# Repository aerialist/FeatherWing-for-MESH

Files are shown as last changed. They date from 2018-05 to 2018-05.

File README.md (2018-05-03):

# FeatherWing-for-MESH

A board to connect Adafruit Feather line of microcontroller boards to Sony MESH GPIO tag.

* https://www.adafruit.com/feather
* http://meshprj.com/en/

It also acts as a GPIO accessory for Sony MESH GPIO tag, featuring three buttons for Digital In, three LED's for Digital Out, a potentiometer for Analog In and another LED for PWM Out.

See [Wiki](https://github.com/aerialist/FeatherWing-for-MESH/wiki) for documentation.

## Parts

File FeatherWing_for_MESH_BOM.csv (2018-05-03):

Part | Value | Device | Package | Description
B1 |  | SWITCH_TACT_SMT4.6X2.8 | BTN_KMR2_4.6X2.8 | SMT Tact Switches
B2 |  | SWITCH_TACT_SMT4.6X2.8 | BTN_KMR2_4.6X2.8 | SMT Tact Switches
B3 |  | SWITCH_TACT_SMT4.6X2.8 | BTN_KMR2_4.6X2.8 | SMT Tact Switches
J1 | NF | CONN_05X2NO_SILK | 2X5_NOSILK | Multi connection point. Often used as Generic Header-pin footprint for 0.1 inch spaced/style header connections
J2 | NF | CONN_05X2NO_SILK | 2X5_NOSILK | Multi connection point. Often used as Generic Header-pin footprint for 0.1 inch spaced/style header connections
JP1 | JUMPER-SMT_2_NC_TRACE_SILK | JUMPER-SMT_2_NC_TRACE_SILK | SMT-JUMPER_2_NC_TRACE_SILK | Normally closed trace jumper
JP2 | JUMPER-SMT_3_1-NC_TRACE_SILK | JUMPER-SMT_3_1-NC_TRACE_SILK | SMT-JUMPER_3_1-NC_TRACE_SILK | Normally closed trace jumper (1 of 2 connections)
JP3 | NF | HEADER-1X16_76MIL | 1X16_ROUND_76MIL | PIN HEADER
JP4 | NF | HEADER-1X1276MIL | 1X12_ROUND_76MIL
LED1 | RED | LEDCHIPLED_0805 | CHIPLED_0805 | LED
LED2 | YELLOW | LEDCHIPLED_0805 | CHIPLED_0805 | LED
LED3 | GREEN | LEDCHIPLED_0805 | CHIPLED_0805 | LED
LED4 | RED | LEDCHIPLED_0805 | CHIPLED_0805 | LED
LED5 | ORANGE | LEDCHIPLED_0805 | CHIPLED_0805 | LED
MS1 | FEATHERWING | FEATHERWING | FEATHERWING
R1 | 280R | RESISTOR0805_NOTHERMALS | 0805_NOTHERMALS | Resistors
R2 | 330R | RESISTOR0805_NOTHERMALS | 0805_NOTHERMALS | Resistors
R3 | 220R | RESISTOR0805_NOTHERMALS | 0805_NOTHERMALS | Resistors
R4 | 280R | RESISTOR0805_NOTHERMALS | 0805_NOTHERMALS | Resistors
R5 | 330R | RESISTOR0805_NOTHERMALS | 0805_NOTHERMALS | Resistors
TM1 | 10kR | TRIMPOTTC33X | TC33X | SMT trimmer potentiometer part number TC33X

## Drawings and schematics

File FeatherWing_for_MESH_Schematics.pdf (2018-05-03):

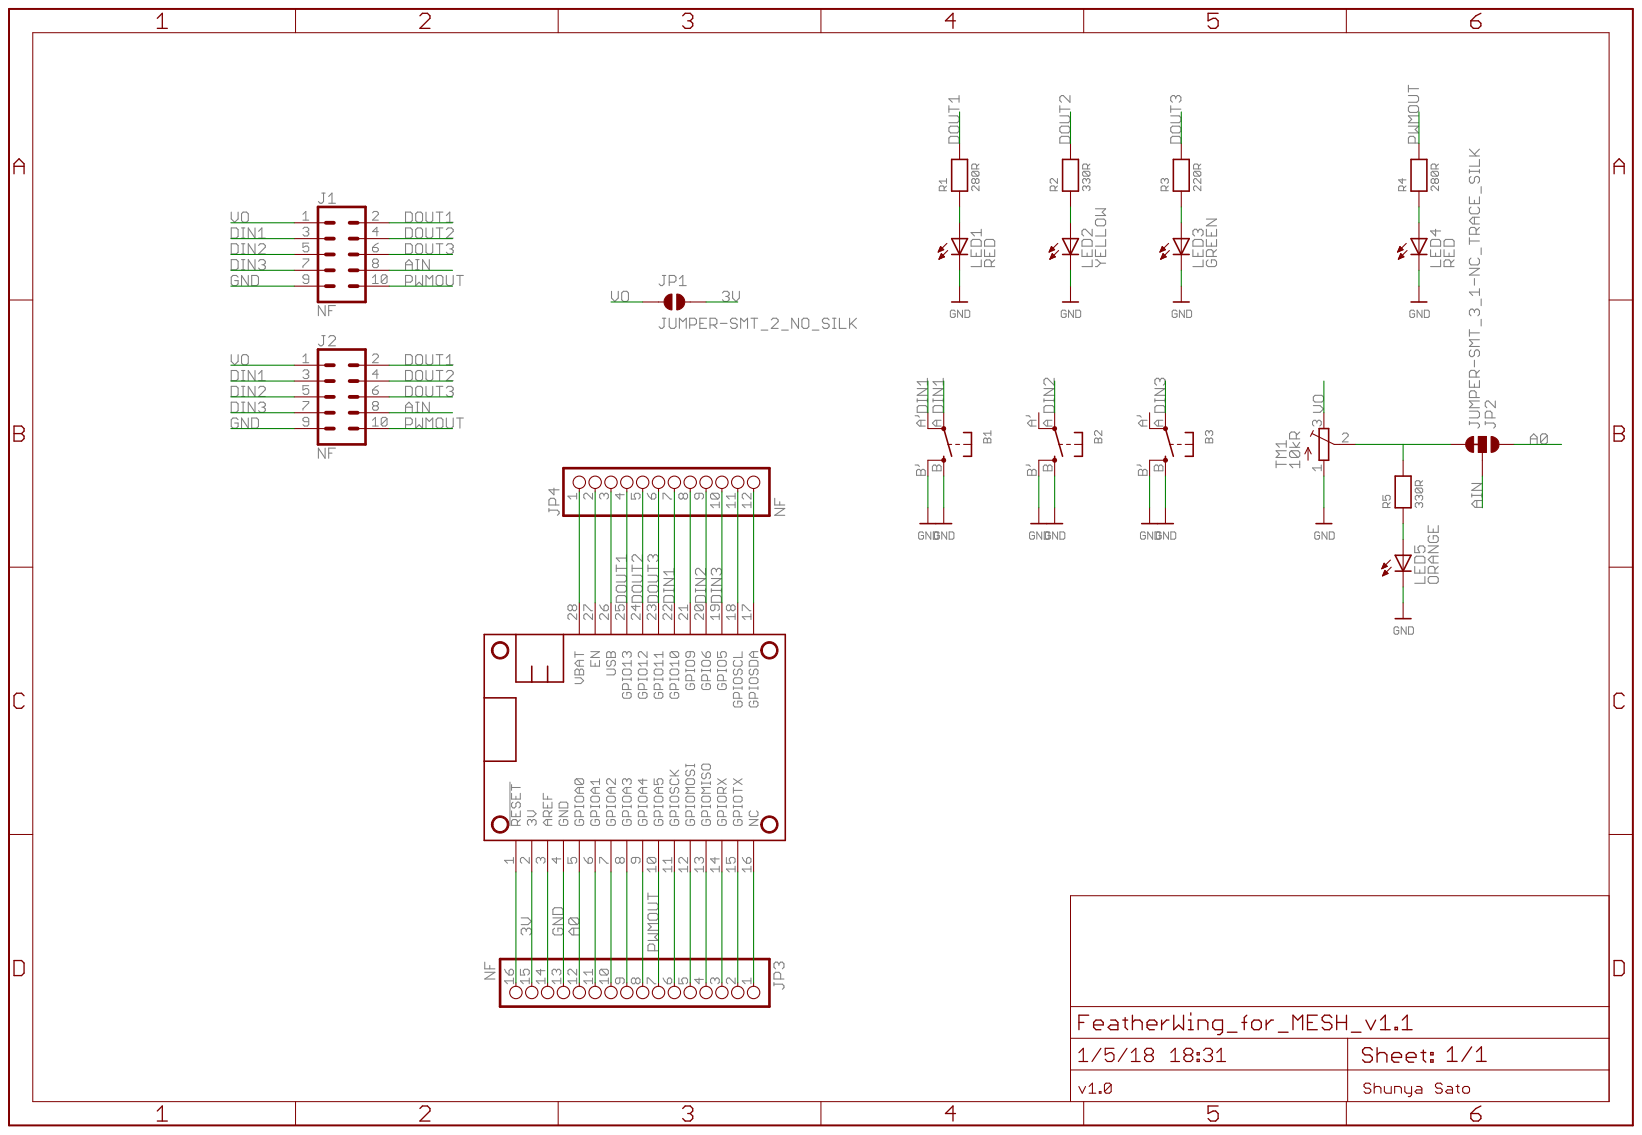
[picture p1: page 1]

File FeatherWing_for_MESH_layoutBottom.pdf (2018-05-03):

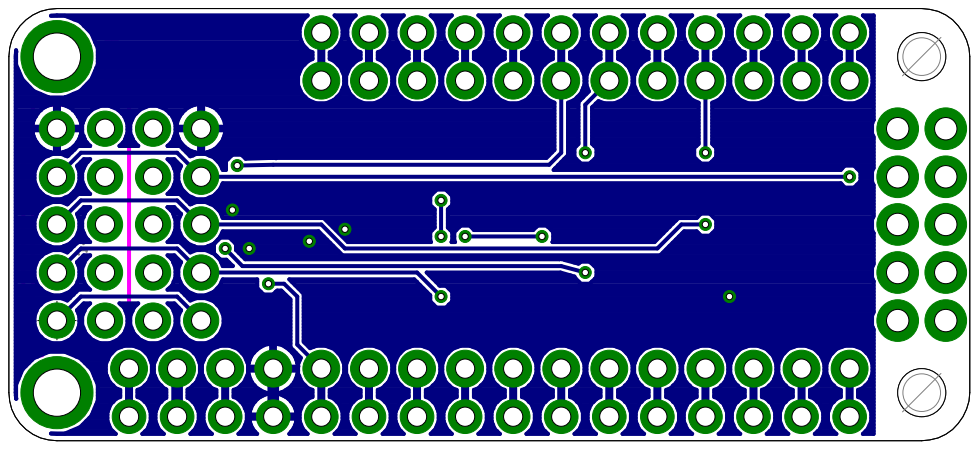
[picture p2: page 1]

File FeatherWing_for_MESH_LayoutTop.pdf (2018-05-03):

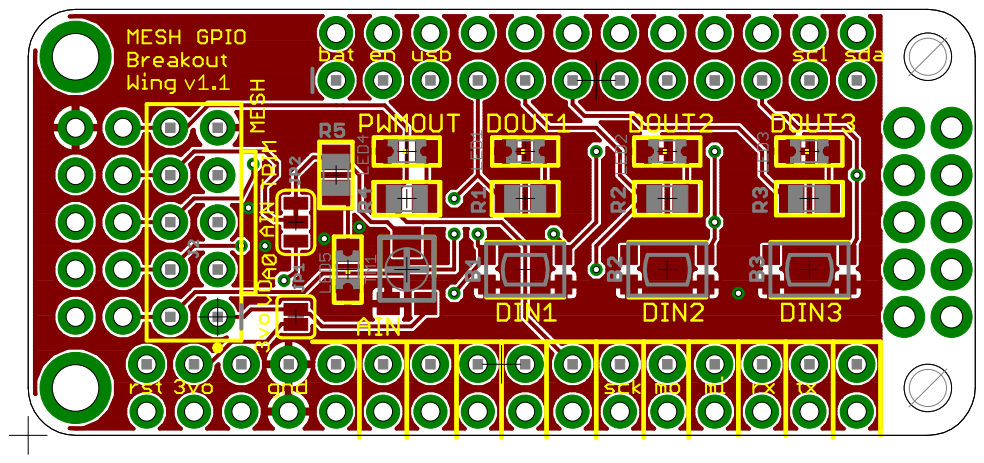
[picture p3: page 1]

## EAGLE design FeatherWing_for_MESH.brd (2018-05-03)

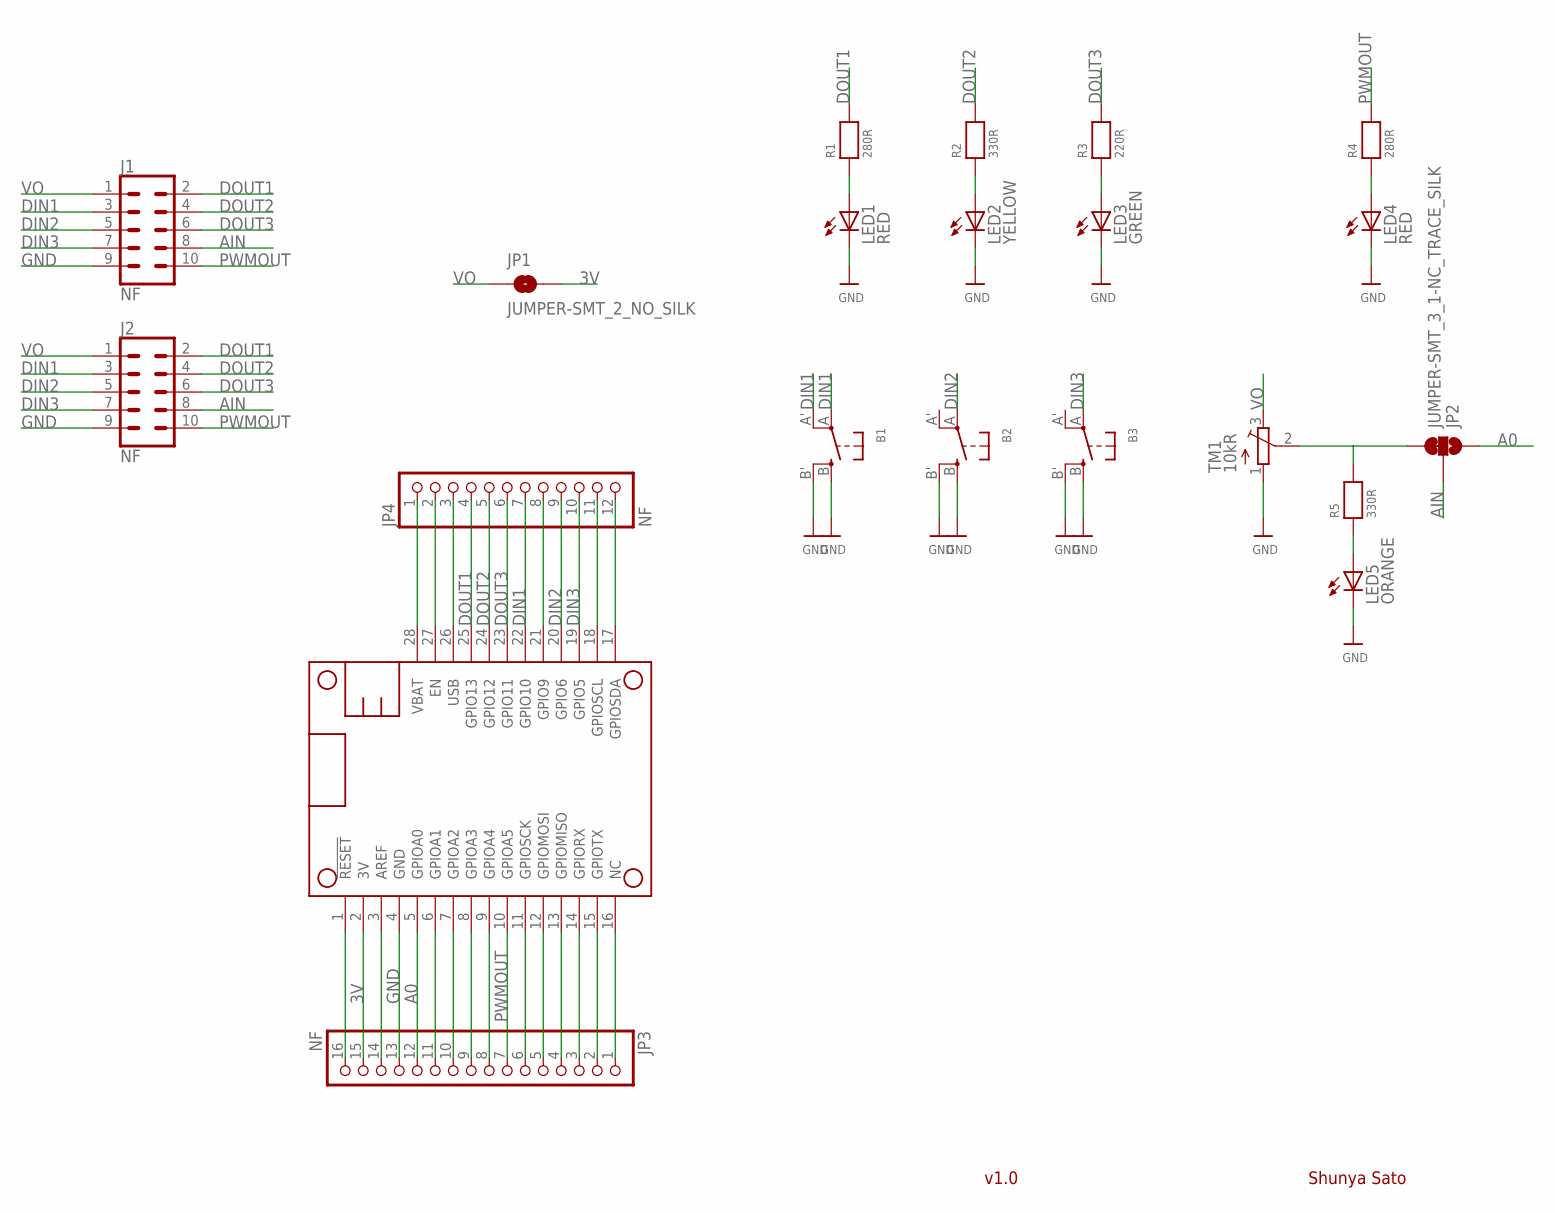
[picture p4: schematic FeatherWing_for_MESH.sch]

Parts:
B1, B2, B3: SWITCH_TACT_SMT4.6X2.8; BTN_KMR2_4.6X2.8
J1, J2: NF; 2X5_NOSILK
JP1: JUMPER-SMT_2_NO_SILK; SMT-JUMPER_2_NO_SILK
JP2: JUMPER-SMT_3_1-NC_TRACE_SILK; SMT-JUMPER_3_1-NC_TRACE_SILK
JP3: NF; 1X16_ROUND_76MIL
JP4: NF; 1X12_ROUND_76MIL
LED1, LED4: RED; CHIPLED_0805
LED2: YELLOW; CHIPLED_0805
LED3: GREEN; CHIPLED_0805
LED5: ORANGE; CHIPLED_0805
MS1: FEATHERWING
R1, R4: 280R; 0805_NOTHERMALS
R2, R5: 330R; 0805_NOTHERMALS
R3: 220R; 0805_NOTHERMALS
TM1: 10kR; TC33X

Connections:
3V: JP1.2, JP3.15, MS1.2 (3V)
A0: JP2.1, JP3.12, MS1.5 (GPIOA0)
AIN: J1.8, J2.8, JP2.2
AREF: JP3.14, MS1.3 (AREF)
DIN1: B1.A, B1.A' (P1), J1.3, J2.3, JP4.7, MS1.22 (GPIO10)
DIN2: B2.A, J1.5, J2.5, JP4.9, MS1.20 (GPIO6)
DIN3: B3.A, J1.7, J2.7, JP4.10, MS1.19 (GPIO5)
DOUT1: J1.2, J2.2, JP4.4, MS1.25 (GPIO13), R1.2
DOUT2: J1.4, J2.4, JP4.5, MS1.24 (GPIO12), R2.2
DOUT3: J1.6, J2.6, JP4.6, MS1.23 (GPIO11), R3.2
GND: B1.B (S), B1.B' (S1), B2.B (S), B2.B' (S1), B3.B (S), B3.B' (S1), J1.9, J2.9, JP3.13, LED1.C, LED2.C, LED3.C, LED4.C, LED5.C, MS1.4 (GND), TM1.1 (A)
unnamed: JP4.2, MS1.27 (EN)
unnamed: JP3.1, MS1.16 (NC)
unnamed: JP3.2, MS1.15 (GPIOTX)
unnamed: JP3.3, MS1.14 (GPIORX)
unnamed: JP3.4, MS1.13 (GPIOMISO)
unnamed: JP3.5, MS1.12 (GPIOMOSI)
unnamed: JP3.6, MS1.11 (GPIOSCK)
unnamed: JP3.8, MS1.9 (GPIOA4)
unnamed: JP3.9, MS1.8 (GPIOA3)
unnamed: JP3.10, MS1.7 (GPIOA2)
unnamed: JP3.11, MS1.6 (GPIOA1)
unnamed: LED1.A, R1.1
unnamed: LED2.A, R2.1
unnamed: JP3.16, MS1.1 (!RESET)
unnamed: JP4.8, MS1.21 (GPIO9)
unnamed: JP4.11, MS1.18 (GPIOSCL)
unnamed: JP4.12, MS1.17 (GPIOSDA)
unnamed: LED3.A, R3.1
unnamed: LED4.A, R4.1
unnamed: JP2.3, R5.2, TM1.2 (S)
unnamed: LED5.A, R5.1
PWMOUT: J1.10, J2.10, JP3.7, MS1.10 (GPIOA5), R4.2
USB: JP4.3, MS1.26 (USB)
VBAT: JP4.1, MS1.28 (VBAT)
VO: J1.1, J2.1, JP1.1, TM1.3 (E)

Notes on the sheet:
Shunya Sato
v1.0

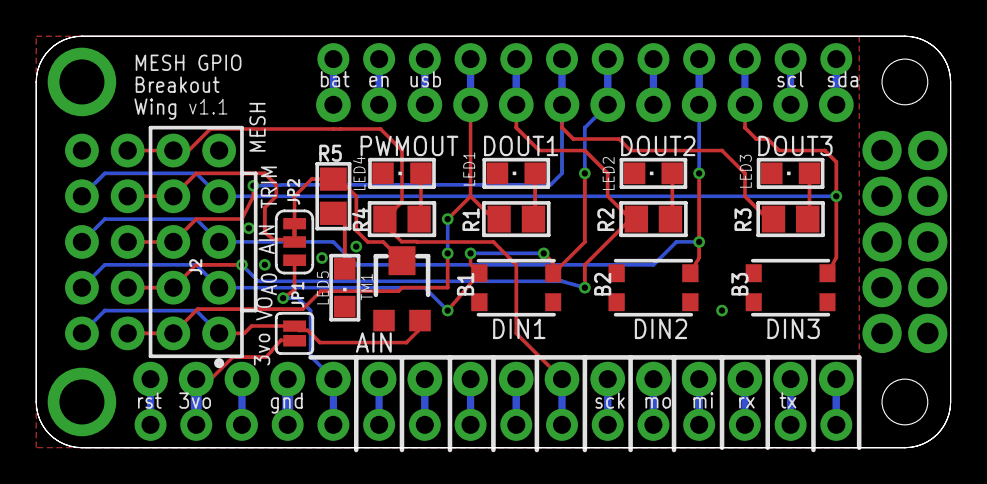
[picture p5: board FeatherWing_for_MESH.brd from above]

Board: 2 copper layers, 50.8 x 22.9 mm, 21 parts (1 on the bottom side), 36 nets.

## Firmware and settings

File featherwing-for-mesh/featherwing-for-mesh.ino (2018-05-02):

// Pin connections
// MESH <-> Feather
#define AIN A0
#define PWMOUT A5
#define DOUT1 13
#define DOUT2 12
#define DOUT3 11
#define DIN1 10
#define DIN2 6
#define DIN3 5

int dins[] = {DIN1, DIN2, DIN3};
int douts[] = {DOUT1, DOUT2, DOUT3};

void setup() {
  Serial.begin(115200);
  Serial.println("Feather Wing for Sony MESH");
  
  // set pin mode of Feather
  // Note that pin naming is from MESH's point of view
  // i.e. DIN is Digital Input for MESH which is OUTPUT for Feather
  pinMode(AIN, OUTPUT);
  pinMode(PWMOUT, INPUT);
  pinMode(DOUT1, INPUT);
  pinMode(DOUT2, INPUT);
  pinMode(DOUT3, INPUT);
  pinMode(DIN1, OUTPUT);
  pinMode(DIN2, OUTPUT);
  pinMode(DIN3, OUTPUT);
  
  digitalWrite(DIN1, HIGH);
  digitalWrite(DIN2, HIGH);
  digitalWrite(DIN3, HIGH);

  //test_din();
}

void loop() {
  // uncomment each lines to test
  // test_din();
  // test_dout();  
  // test_pwmout();
  // test_ain();
}

void test_ain(void){
  for(int i=0; i<255; i++){
    analogWrite(AIN, i);
    Serial.println(i);
    delay(30);
  }
  for(int i=255; i<0; i--){
    analogWrite(AIN, i);
    Serial.println(i);
    delay(30);
  }
}

void test_pwmout(void){
  digitalWrite(DIN1, LOW);
  for (int i=0; i<10; i++){
    unsigned long duration = pulseIn(PWMOUT, HIGH);
    Serial.println(duration);
    delay(1000);  
  }
  digitalWrite(DIN1, HIGH);
  delay(5000);
}

void test_dout(void){
  for(int i=0; i<3; i++){
    digitalWrite(dins[i], LOW);
    delay(3000);
    print_dout();
    delay(1000);
    digitalWrite(dins[i], HIGH);
    delay(3000);
    print_dout();
  }
}

void print_dout(void){
  Serial.println("DOUT status");
  for (int i=0; i<3; i++){
    int btn = digitalRead(douts[i]);
    Serial.print(i);
    Serial.print(": ");
    Serial.println(btn);    
  }
}

void test_din(void){
  int delaytime = 3000;

  Serial.println("Going to test DIN");
  for (int i=0; i<3; i++){
    digitalWrite(dins[i], LOW);
    Serial.print(i);
    Serial.println(": LOW");
    delay(delaytime);
    digitalWrite(dins[i], HIGH);
    Serial.print(i);
    Serial.println(": HIGH");
    delay(delaytime);
  }
}

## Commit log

2018-02-15 Initial commit. v1.0
    [FeatherWing_for_MESH.brd, FeatherWing_for_MESH.sch, FeatherWing_for_MESH_v1.0_BOM_seeed.csv]
2018-05-02 Add Arduino example
2018-05-03 v1.1 Add Mesh pin1 marking, move LEDs away from buttons, default not to connect 3V and Vout. Panelized garber.
    [FeatherWing_for_MESH.brd, FeatherWing_for_MESH.sch, FeatherWing_for_MESH_v1.0_BOM_seeed.csv]
2018-05-03 Add BOM and gitignore
    [FeatherWing_for_MESH_BOM.csv]

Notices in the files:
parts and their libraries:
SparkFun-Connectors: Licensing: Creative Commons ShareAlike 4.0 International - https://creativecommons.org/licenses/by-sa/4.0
